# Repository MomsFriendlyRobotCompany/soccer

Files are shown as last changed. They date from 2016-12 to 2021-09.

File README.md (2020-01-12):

# Soccer

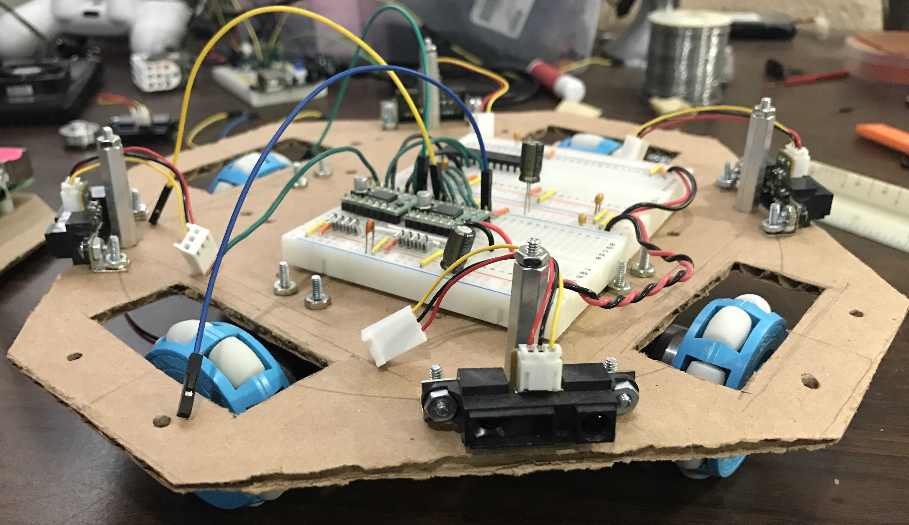
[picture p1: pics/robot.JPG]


My robot has seen better days and is currently torn appart. However, I plan to rebuild
it. Right now I am re-working it and put it into a like "bread board" configuration so
I can get everything setup again correctly.

## Documentation

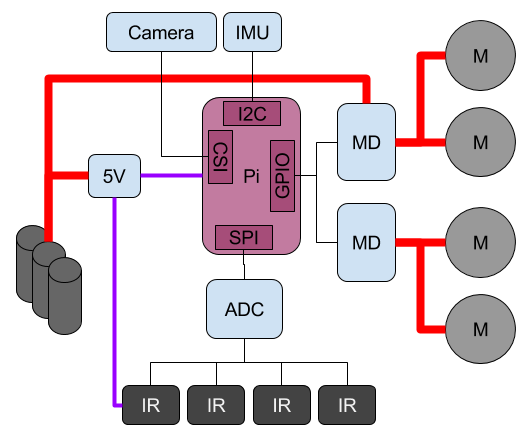
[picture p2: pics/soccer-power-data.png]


- main battery is a 12V NiMH
- a Pololu 5v, 2.6A buck converter supplying power to both RPi and the IR sensors
- the Pi is used to provide 3.3V to the IMU and ADC
- a MCP3208 ADC (8 channel, 12b) is used to read the IR sensors
- 4 geared DC brushed motors (138 rmp @ 12V) drive the robot
- Omni wheels from www.kornylak.com allow holonomic movement (no velocity constraint)
- Raspberry Pi Camera
- NXP IMU from Adafruit

### Other Docs

- [Markdown docs](./docs/Markdown)
- [Jupyter notebooks](./docs/ipython)

# Licenses

**Note:** The software, hardware, and documentation are under different licenses.

## Software

**The MIT License (MIT)**

Copyright (c) 2014 Kevin J. Walchko

Permission is hereby granted, free of charge, to any person obtaining a copy of
this software and associated documentation files (the "Software"), to deal in
the Software without restriction, including without limitation the rights to
use, copy, modify, merge, publish, distribute, sublicense, and/or sell copies
of the Software, and to permit persons to whom the Software is furnished to do
so, subject to the following conditions:

The above copyright notice and this permission notice shall be included in all
copies or substantial portions of the Software.

THE SOFTWARE IS PROVIDED "AS IS", WITHOUT WARRANTY OF ANY KIND, EXPRESS OR
IMPLIED, INCLUDING BUT NOT LIMITED TO THE WARRANTIES OF MERCHANTABILITY, FITNESS
FOR A PARTICULAR PURPOSE AND NONINFRINGEMENT. IN NO EVENT SHALL THE AUTHORS OR
COPYRIGHT HOLDERS BE LIABLE FOR ANY CLAIM, DAMAGES OR OTHER LIABILITY, WHETHER
IN AN ACTION OF CONTRACT, TORT OR OTHERWISE, ARISING FROM, OUT OF OR IN
CONNECTION WITH THE SOFTWARE OR THE USE OR OTHER DEALINGS IN THE SOFTWARE.

## Hardware and Documentation

<a rel="license" href="http://creativecommons.org/licenses/by-sa/4.0/">
	
</a>
<br />This work is licensed under a <a rel="license" href="http://creativecommons.org/licenses/by-sa/4.0/">Creative Commons Attribution-ShareAlike 4.0 International License</a>.

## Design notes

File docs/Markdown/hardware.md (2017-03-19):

# Body

My robot is broken up into 2 levels. The top level (seen on the left) which
will have the RPi, camera, and battery (easier to change/charge). The bottom
level will have motor drivers, power system, IR sensors, ADC, and compass.

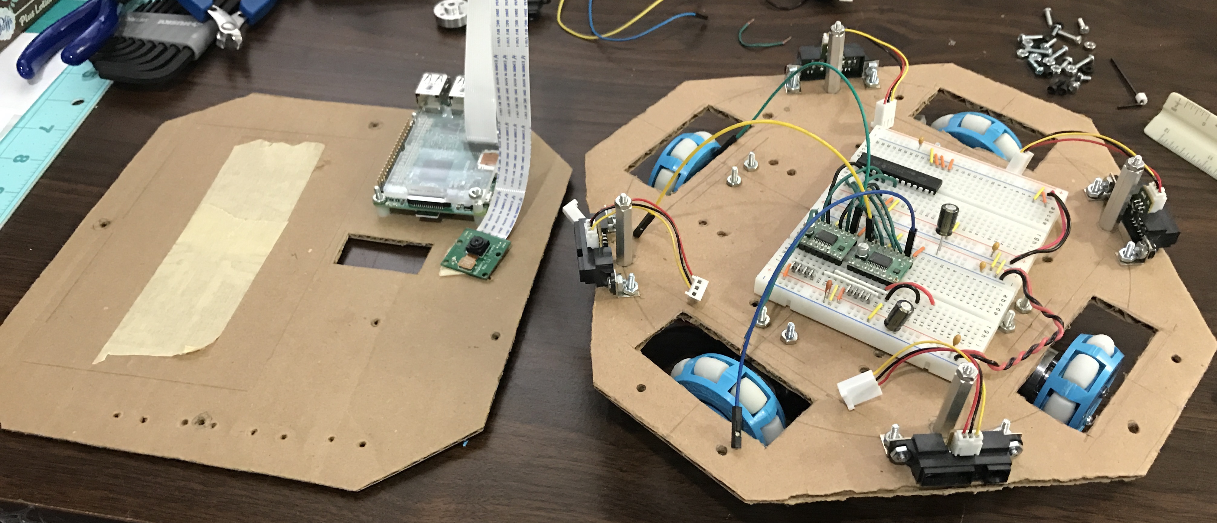
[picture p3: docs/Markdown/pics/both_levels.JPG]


A closer look at the bottom level is below:



The hubs and the wheels are joined together by some #4-40 x 1 inch bolts. I had
to drill a couple of holes through the center of the wheel so the bolts could
go through.

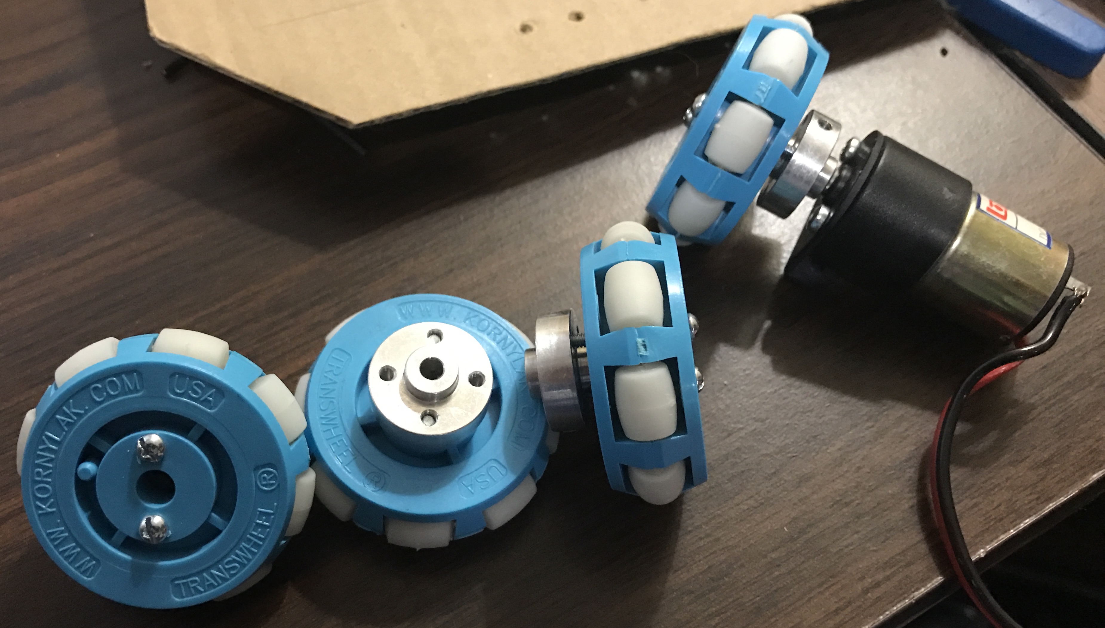
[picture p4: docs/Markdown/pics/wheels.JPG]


# Raspberry Pi

RPI 3

I am currently using a 1.2 GHz quad core [RPi 3](https://www.adafruit.com/products/3055) (ARMv8) as the main board running the lite version of Raspbian. It has on-board:

* 802.11n Wifi
* Bluetooth 4.1 BLE

## Camera Interface (CSI)

* [PiCamera](https://www.adafruit.com/products/3099) is used for video odometry (currently have version 1, 5 Mpixels but moving to 8 Mpixels)

## I2C

The following is on the I2C bus:

* [MCP23017 16b I/O Expander](https://www.adafruit.com/products/732): 0x20
* TBD - AHRS Compass ...need to get one

## GPIO

The RPi has both Pi pin numbers and BCM pin numbers assigned to its GPIO.

|BCM| Use  | Pi | Pi | Use |BCM|
|---|---|----|----|-----|---|
| | 3v3  |  1 |  2 | 5v  | |
| 2 | SDA  |  3 |  4 | 5v  | |
| 3 | SCL  |  5 |  6 | GND | |
| 4 | PWM0 |  7 |  8 | TX  | 14|
| | GND  |  9 | 10 | RX  | 15|
| 17| PWM1 | 11 | 12 | | 18|
| 27| PWM2 | 13 | 14 | GND | |
| 22| PWM3 | 15 | 16 | | 23|
| | 3v3  | 17 | 18 | | 24|
| 10| MOSI | 19 | 20 | GND | |
|  9| MISO | 21 | 22 | | 25|
| 11| SCLK | 23 | 24 | CE0 |  8|
| | GND  | 25 | 26 | CE1 |  7|
|  0| A0 | 27 | 28 | |  1|
|  5| B0 | 29 | 30 | GND | |
|  6| A1 | 31 | 32 | | 12|
| 13| B1 | 33 | 34 | GND | |
| 19| | 35 | 36 | | 16|
| 26| | 37 | 38 | | 20|
| | GND  | 39 | 40 | | 21|

# Sensors

* [Sharp GP2Y0A21YK0F IR](https://www.adafruit.com/products/164) sensors give 10-80 cm (3.9-31.5 in)
* Pololu [ACS711LC Current sensor](https://www.pololu.com/product/2198) measures up to +/-25 A and up to 30 V

# Motion

* Pololu [TB6612FNG Dual Motor Driver](https://www.pololu.com/product/713) provides 4.5-13.5V at 1A continuous (3A peak) current.
* Motors currently are 12V 130 rpm gear motors

# Parts

Here is a parts list of **key components** that I am using. I am not listing wires, bread boards, cables, etc. Also note, I have rounded up the costs (i.e., $4.95 => $5).

| Part | Source | Number | Item Cost | Sum | Notes |
| ---  | --- | --- | --- | --- | --- |
| RPi v3 | [Adafruit](https://www.adafruit.com) | 1 | $40 | $40 | Main board, has wifi and bluetooth already |
| Pi Camera | [Adafruit](https://www.adafruit.com) | 1 | $30 | $30 | Currently have old 5 Mpixel, will upgrade to newer 8 Mpixel |
| PWM/Servo Driver, 16 Channels, 12 bit resolution (PCA9685) | [Adafruit](https://www.adafruit.com) | 1 | $15 | $15 | Controls motors and servos over I2C |
| MCP23017 (16 I/O port expander, I2C) | [Adafruit](https://www.adafruit.com) | 1 | $3 | $3 | Used to increase the digital I/O |
| TB6612FNG Dual Motor Driver | [Pololu](https://www.pololu.com/product/713) | 2 | $5 | $10 | Logic level 3.3V, motors 4.5-13V @ 1A continous (3A peak) per channel |
| 5V, 5A Buck Converter (D24V50F5)  | [Pololu](https://www.pololu.com) | 1 | $15 | $15 | For powering my electronics |
| 12V, 5A Boost Converter (U3V50F12) | [Pololu](https://www.pololu.com) | 1 | $14 | $14 | For powering my motors (future 12V motors) |
| Sharp IR | [Pololu](https://www.pololu.com) | 8 | $10 | $80 | Range 10-80 cm |
| PS4 Controller | [Walmart](http://www.walmart.com) | 1 | $54 | $54 | |
| Micro SD (32 GB) | [Walmart](http://www.walmart.com) | 1 | $12 | $12 | |

---

<p align="center">
	<a rel="license" href="http://creativecommons.org/licenses/by-sa/4.0/">
		
	</a>
	<br />This work is licensed under a <a rel="license" href="http://creativecommons.org/licenses/by-sa/4.0/">Creative Commons Attribution-ShareAlike 4.0 International License</a>.
</p>

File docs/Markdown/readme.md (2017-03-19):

# Documentation

- [Software](./software.md)
- [Hardware](./hardware.md)
- [PyGecko](./pygecko.md)
- [History](./history.md)

---

A highlevel overview of how the robot works is shown below

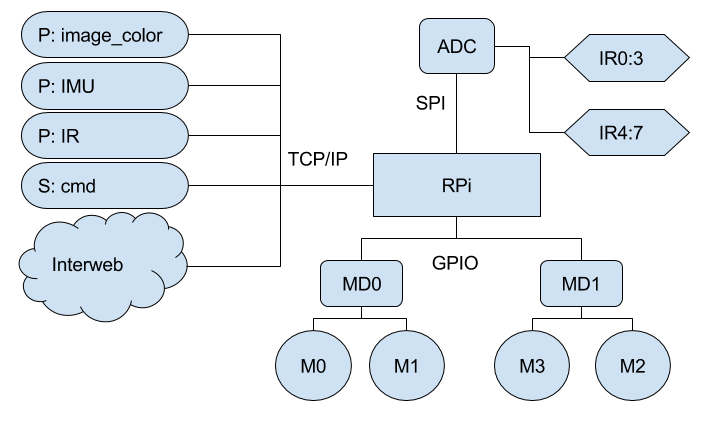
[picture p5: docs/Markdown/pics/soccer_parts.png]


- P: publish pygecko messages
- S: subscribe to pygecko messages

The publish and subscribe architecture is drawn from ROS ([Robotic Operating System](http://www.ros.org/)) where multiple/modular processess run a robot and
they communicate via a publish/subscribe architecture. I don't use ROS because
it is a pain to install on systems it is not designed for. I use [PyGecko](https://github.com/walchko/pygecko) which implements some of the basic
useful features of ROS.

A **nonholonomic system** in physics and mathematics is a system whose state
depends on the path taken in order to achieve it. [Ref](https://en.wikipedia.org/wiki/Nonholonomic_system)
Think about how a car (nonholonomic) must parallel park ... wouldn't it be easier
if it could drive sideways! Basically, a car has a velocity constraint in its
movement.

Since this robot can move in any direction and is not required to follow a specific
path, it is a **holonomic system** and is a common design in robotic soccer.

---

<p align="center">
	<a rel="license" href="http://creativecommons.org/licenses/by-sa/4.0/">
		
	</a>
	<br />This work is licensed under a <a rel="license" href="http://creativecommons.org/licenses/by-sa/4.0/">Creative Commons Attribution-ShareAlike 4.0 International License</a>.
</p>

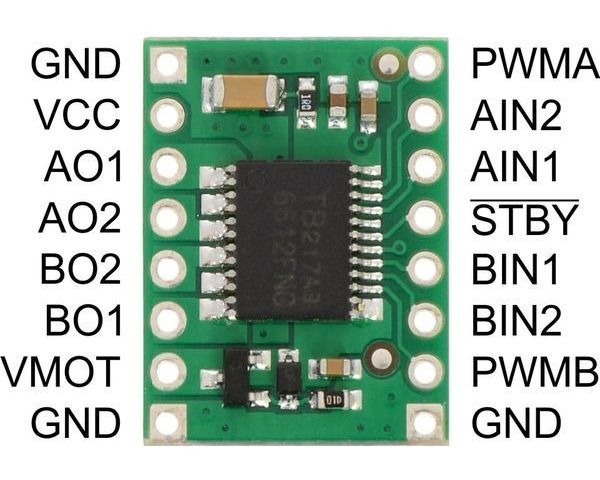
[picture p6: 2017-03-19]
docs/motor_driver/TB6612FNG.jpg

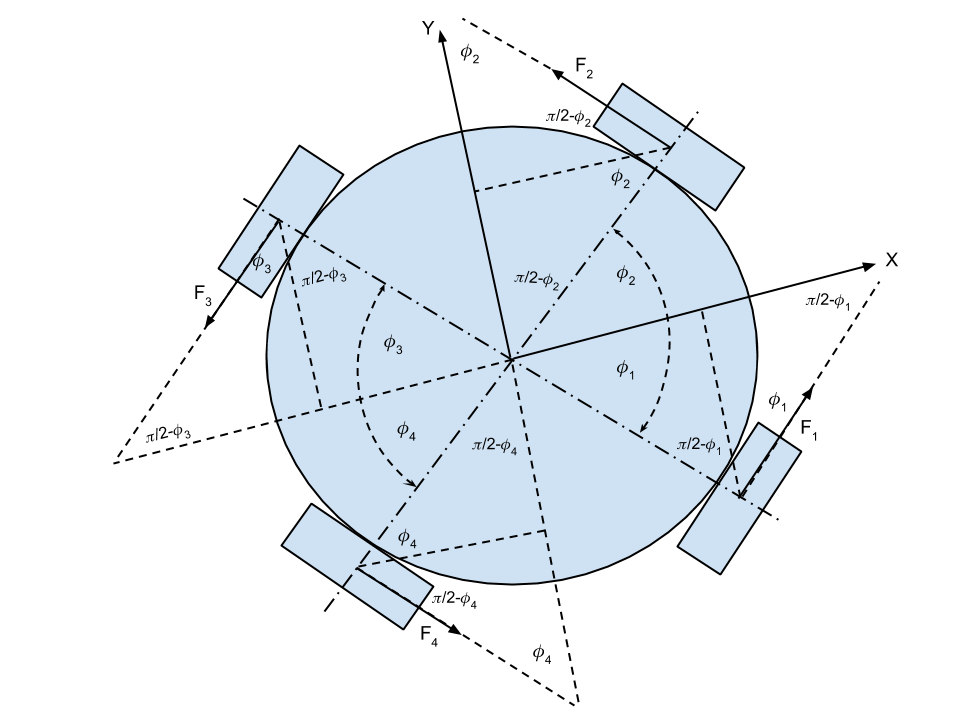
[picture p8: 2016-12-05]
docs/ipython/pics/omni_robot_force_cs.png

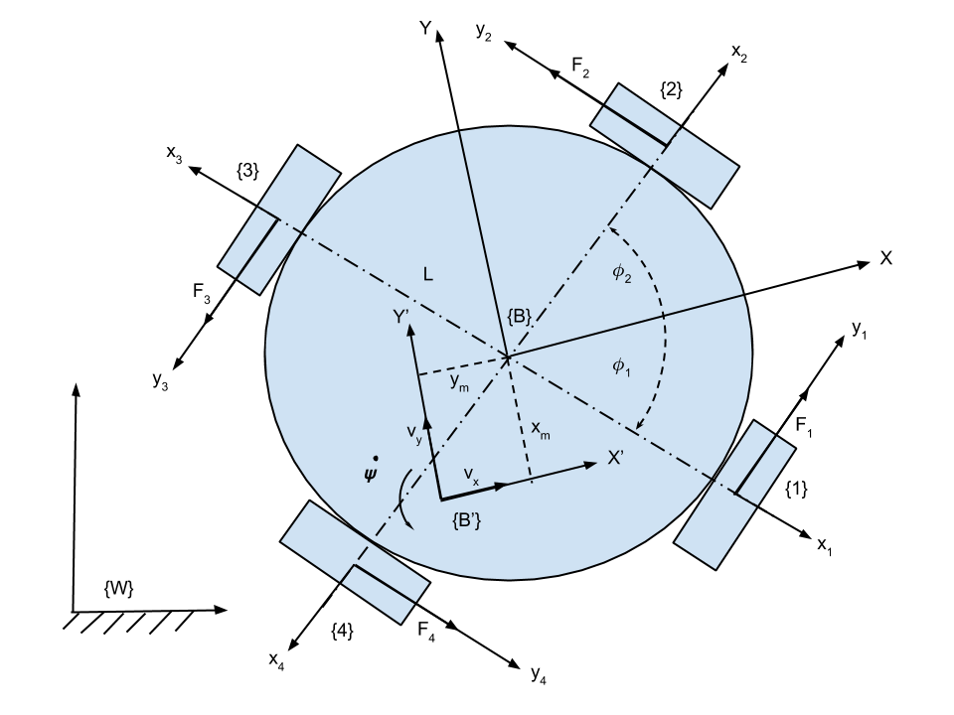
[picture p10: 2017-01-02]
docs/ipython/pics/omni_robot_cs.png

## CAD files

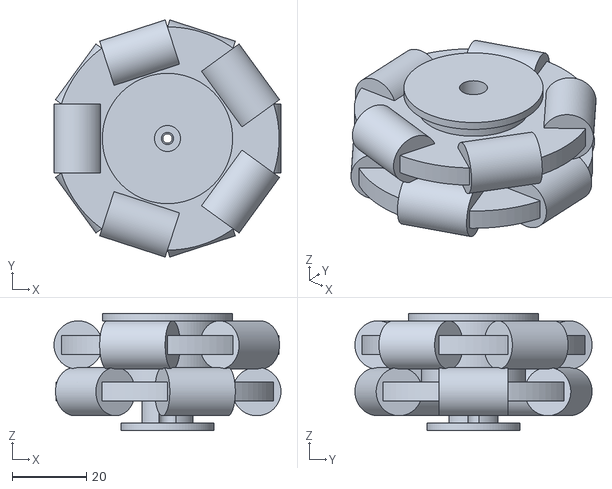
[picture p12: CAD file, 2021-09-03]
mechanical/omni-wheel.stl
61.0 x 63.7 x 31.5

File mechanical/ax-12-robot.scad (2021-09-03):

$fn=90;

module ax12(){
    // sort of center mass
    color("dimgray") translate([0,0,0]) import("DYNAMIXEL_AX-12A.STL");
    color("dimgray") translate([0,0,20]) import("omni-wheel.stl");
}

module base(dia){
    corner = 70;
    sx = 30;
    sy = 34;
    difference()
    {
        /* cylinder(d=dia, h=4); */
        translate([-dia/2,-dia/2,0]) cube([dia,dia,4]);
        /* translate([0,0,-1]) cylinder(d=dia/3, h=6); */
        for (i=[45, 45+90, 45+180, 45+270]){
            color("red") rotate([0,0,i]) translate([100,0,0]) translate([-corner/2,-corner/2,-1]) cube([corner,corner,6]);
            color("red") rotate([0,0,i]) translate([40,0,0]) translate([-sx/2,-sy/2,-1]) cube([2*sx,sy,6]);
        }
    }
}

base(175);


for (i=[45, 45+90, 45+180, 45+270]){
    rotate([0,0,i]) translate([-45,0,0]) rotate([0,-90,0]) ax12();
}

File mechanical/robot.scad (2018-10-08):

$fn=90;

module M3(t){
    dia = 3.5;
    sdia = 8.5;  // counter sink dia
    cylinder(3*t, d=dia, center=true);  // M3
    translate([0,0,2]) cylinder(3*t, d=sdia, center=false);  // screw driver
}

module M2(t){
    dia = 2.5;
    sdia = 6;  // counter sink dia
    cylinder(3*t, d=dia, center=true);  // M2
    translate([0,0,2]) cylinder(3*t, d=sdia, center=false);  // screw driver
}

// DC motor
module motor(){
    rotate([0,90,0]) {
        color("silver") translate([0,0,-16]) cylinder(h=12,d=4);  // shaft
        color("gray") translate([0,0,-4]) cylinder(h=4, d=9);     // nubbin
        difference(){
            color("gray") cylinder(h=20, d=25);                   // gears
            translate([21/2,0,-1]) cylinder(h=5, d=3);            // mounting hole
            translate([-21/2,0,-1]) cylinder(h=5, d=3);           // mounting hole
        }
        color("silver") translate([0,0,20]) cylinder(h=22, d=23); // motor
        color("gray") translate([0,0,42]) cylinder(h=3, d=10);    // motor nubbin
    }
}

// metal hub between wheel and motor
module hub(){
    color("silver") rotate([0,90,0]) {
        cylinder(h=3, d=9);
        translate([0,0,3]) cylinder(h=6, d=22);
        translate([0,0,9]) cylinder(h=3, d=9);
    }
}

// omni wheel
module wheel(){
    rotate([0,90,0]) color("lightblue") difference(){
        cylinder(h=17, d=49, center=true);
        cylinder(h=20, d=7, center=true);
    }

    for(a = [0:7]){
        rotate([a*45,0,0]) translate([0,22,0]) color("white") cylinder(h=12,d=9, center=true);
    }
}

// combined motor, hub, and wheel assembly
module wheel_seg(){
    motor();
    translate([-16,0,0]) hub();
    translate([-16-17/2,0,0]) wheel();
}

// mounting frame for motor
module motor_mnt(){
    difference(){
        cube([2,30,30]);
    }
}

module ir_mnt(){
    translate([-3/2,-25/2,0]) cube([3,25,10]);
}

module motor_plate(dia, draw=false){
    if (draw){
        translate([0,0,25/2+4]){
            mdis = [-dia/4-5,0,0];
            translate(mdis) wheel_seg();
            rotate([0,0,90]) translate(mdis) wheel_seg();
            rotate([0,0,180]) translate(mdis) wheel_seg();
            rotate([0,0,270]) translate(mdis) wheel_seg();
        }
    }

    difference(){
        cylinder(h=3, d=dia);

        // center
        cylinder(h=9, d=dia/2, center=true);

        // wheel cut outs
        translate([80,0,0]) cube([20,55,20], center=true);
        rotate([0,0,90]) translate([80,0,0]) cube([20,55,20], center=true);
        rotate([0,0,180]) translate([80,0,0]) cube([20,55,20], center=true);
        rotate([0,0,270]) translate([80,0,0]) cube([20,55,20], center=true);

        // mounts
        for(a=[0:3]){
            rotate([180,0,0]) rotate([0,0,90*a+45]) translate([0.8*dia/2,0,-3]) M3(20);
        }
    }

    /* for(a=[0:3]){
        rotate([180,0,0]) rotate([0,0,90*a+45]) translate([0.8*dia/2,0,-3]) M3(20);
    } */

    for(a=[0:3]){
        rotate([0,0,90*a]) translate([-57.5,-15,0]) motor_mnt();
        // rotate([0,0,90*a+45]) translate([0.8*dia/2,0,3]) ir_mnt();
    }
}

motor_plate(200, false);

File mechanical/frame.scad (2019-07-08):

module wheel(){
    thick = 17;  // mm
    dia = 50.8;
    cylinder(h=thick, d=dia);
}

module motor(){
    cylinder(h=60, d=25);
}

module mw(angle){
    rotate([90,0,angle]){
        motor();
        translate([0,0,60]) wheel();
    }
}

translate([0,-20,0]) mw(0);
translate([20,0,0]) mw(90);
translate([0,20,0]) mw(180);
translate([-20,0,0]) mw(270);

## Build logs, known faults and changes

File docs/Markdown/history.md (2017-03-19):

# History

Long ago, I hacked some old servos to make them continue turn and used them
to drive this robot. They worked okay, but I wanted to replace them with some
good DC motors.

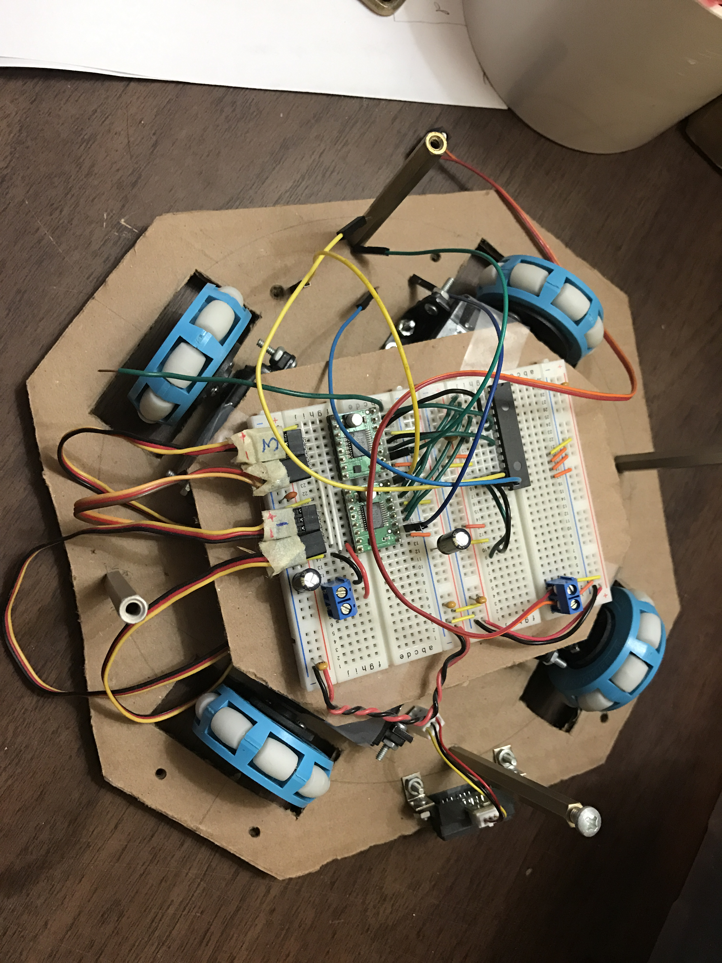
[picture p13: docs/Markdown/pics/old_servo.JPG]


This was a simple breadboard I setup to test out my new DC motors that replaced
the old hacked servos.

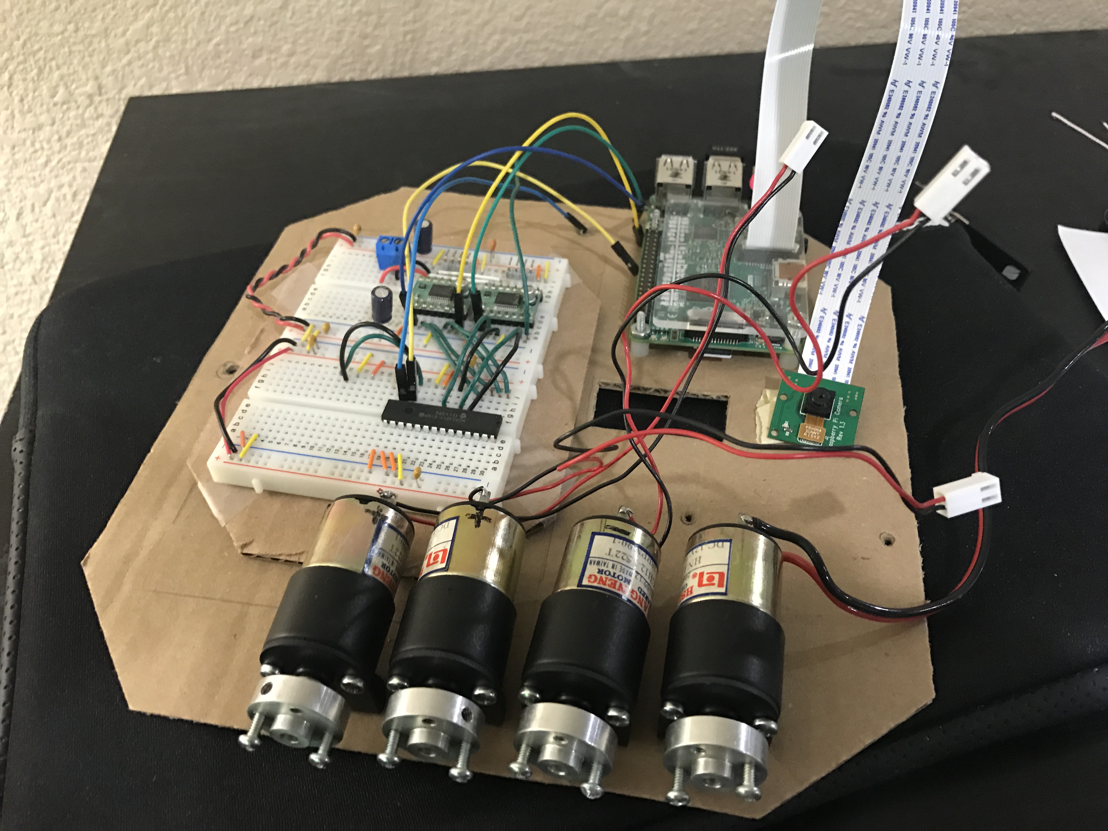
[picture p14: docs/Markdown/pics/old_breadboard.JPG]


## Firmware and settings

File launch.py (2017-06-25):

#!/usr/bin/env python
# 7 Jan 2017

from __future__ import division
from __future__ import print_function
from multiprocessing import Process
from Soccer import SoccerRobot
from pygecko import ZmqClass as zmq
from pygecko import Messages as Msg
import time


def soccer():
	md_pins = [
		17, 18,  # m0 pwm a, b
		22, 23,  # m1 pwm a, b
		24, 25,  # m0 a, b
		26, 27   # m1 a, b
	]
	robot = SoccerRobot(md_pins)

	cmd_sub = zmq.Sub(topics=['cmds'], connect_to=('0.0.0.0', 9000))
	# telemetry_pub = zmq.Pub(bind_to=('0.0.0.0', 9010))

	while True:
		robot.loop_once()

		# get info
		topic, msg = cmd_sub.recv()
		if msg:
			print('msg:', topic, msg)

			if topic == 'quit':
				self.shutdown()
				break
			elif topic == 'cmd':
				# need logic for command
				cmd = self.makeCmd(msg)
				self.md.setMotors(*cmd)


def main():
	try:
		robot = Process(target=soccer).start()
	except KeyboardInterrupt:
		robot.join(0.1)
		if robot.is_alive():
			robot.terminate()

if __name__ == '__main__':
	main()

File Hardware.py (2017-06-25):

#!/usr/bin/python

from __future__ import division
from __future__ import print_function
import platform
import os
from mcp3208 import MCP3208

# if platform.system().lower() == 'linux' and 'CI' not in os.environ:
try:
	if 'CI' in os.environ or platform.system() != 'Linux':
		raise ImportError()
	# from Adafruit_MCP230XX import Adafruit_MCP230XX as MCP230XX
	import RPi.GPIO as GPIO
	from RPi.GPIO import PWM

except ImportError:
	from fake_rpi import GPIO
	from fake_rpi.PWM import PWM


class AnalogIR(object):
	"""
	Read IR sensors on adc inputs
	"""
	def __init__(self):
		self.adc = MCP3208()
		self.ir = {}
		for key in ['front', 'right', 'back', 'left']:
			self.ir[key] = 0

	def read(self):
		for pin, key in enumerate(self.ir):
			# ir.append(self.adc.read(pin))
			# print('read >>', pin, key)
			self.ir[key] = self.adc.read(pin)

		return self.ir


class DigitalIR(object):
	"""
	Read IR sensors on digital inputs

	Pololu sds01a 0-5 cm pwr 3V output max 3V
	Sharp xxx 0-15 cm pwr 5V output max 3V - digital gives 3 inch range
	"""
	def __init__(self, pins):
		GPIO.setwarnings(False)
		GPIO.setmode(GPIO.BCM)
		self.pins = pins
		GPIO.setup(self.pins, GPIO.IN)

	def read(self):
		ir = [0]*len(self.pins)
		# for p in self.pins: ir.append(GPIO.input(p))
		for pin in range(self.pins):
			ir[pin] = self.adc.read(pin)
		return ir


class MotorDriver(object):
	"""
	This uses RPI.GPIO
	"""
	STOP    = 0
	FORWARD = 1
	REVERSE = 2
	COAST   = 3

	def __init__(self, pwm0, pwm1, pwm2, pwm3, a0, b0, a1, b1):
		"""
		"""
		# self.mux = MCP230XX(0x20, 16, 1)
		#
		# for pin in range(0, 15):
		# 	self.mux.config(pin, GPIO.OUT)

		# this can be:
		# BOARD -> Board numbering scheme. The pin numbers follow the pin numbers on header P1.
		# BCM -> Broadcom chip-specific pin numbers.
		GPIO.setmode(GPIO.BCM)  # Pi cover uses BCM pin numbers, GPIO.BCM = 11
		GPIO.setup([pwm0, pwm1, pwm2, pwm3], GPIO.OUT)  # GPIO.OUT = 0

		freq = 100.0  # Hz
		self.motor0 = PWM(pwm0, freq)
		self.motor1 = PWM(pwm1, freq)
		self.motor2 = PWM(pwm2, freq)
		self.motor3 = PWM(pwm3, freq)

		self.motor0.start(0)
		self.motor1.start(0)
		self.motor2.start(0)
		self.motor3.start(0)

		self.ctl = [a0, b0, a1, b1]

		GPIO.setup([a0, b0, a1, b1], GPIO.OUT)  # GPIO.OUT = 0
		# self.a0 = a0
		# self.b0 = b0
		# self.a1 = a1
		# self.b1 = b1

		# GPIO.output(self.a0, GPIO.LOW)
		# GPIO.output(self.b0, GPIO.LOW)
		# GPIO.output(self.a1, GPIO.LOW)
		# GPIO.output(self.a1, GPIO.LOW)

		for pin in self.ctl:
			GPIO.output(pin, GPIO.LOW)

	def __del__(self):
		print('motor drive ... bye')
		self.allStop()
		self.motor0.stop()
		self.motor1.stop()
		self.motor2.stop()
		self.motor3.stop()
		GPIO.cleanup()

	def clamp(self, x, minimum=0, maximum=100):
		"""
		Clamps a PWM from 0-100 and puts it into the right servo usec timing.
		"""
		# minimum = 0
		# maximum = 100
		return 0 if x == 0 else max(minimum, min(x, maximum))

	def setMotors(self, m0, m1, m2, m3):
		"""
		Takes 4 tuples (shown below) for each motor.

		tuple: (dir, duty)

		MotorDriver.STOP    = 0
		MotorDriver.FORWARD = 1
		MotorDriver.REVERSE = 2
		MotorDriver.COAST   = 3
		"""
		# if not 'dir' in m0 or not 'duty' in m0: return
		# low = 0
		# high = 100

		# print(m0, m1, m2, m3)

		# set mux
		# val = m3['dir'] << 6 | m2['dir'] << 4 | m1['dir'] << 2 | m0['dir']
		# val = m3[0] << 6 | m2[0] << 4 | m1[0] << 2 | m0[0]
		# self.mux.write8(val)
		# GPIO.output(self.a0, m0[0])
		# GPIO.output(self.b0, m1[0])
		# GPIO.output(self.a1, m2[0])
		# GPIO.output(self.b1, m3[0])
		#
		# # set pwm
		# pwm = self.clamp(m0[1])
		# self.motor0.ChangeDutyCycle(pwm)
		#
		# pwm = self.clamp(m1[1])
		# self.motor1.ChangeDutyCycle(pwm)
		#
		# pwm = self.clamp(m2[1])
		# self.motor2.ChangeDutyCycle(pwm)
		#
		# pwm = self.clamp(m3[1])
		# self.motor3.ChangeDutyCycle(pwm)

		for pin, cmd, motor in zip(self.ctl, [m0, m1, m2, m3], [self.motor0, self.motor1, self.motor2, self.motor3]):
			GPIO.output(pin, cmd[0])
			pwm = self.clamp(cmd[1])
			motor.ChangeDutyCycle(pwm)

	def allStop(self):
		"""
		"""
		# self.mux.write8(0)
		# GPIO.output(self.a0, GPIO.LOW)
		# GPIO.output(self.b0, GPIO.LOW)
		# GPIO.output(self.a1, GPIO.LOW)
		# GPIO.output(self.a1, GPIO.LOW)
		for pin in self.ctl:
			GPIO.output(pin, GPIO.LOW)

		stop = (0, 0)
		self.setMotors(stop, stop, stop, stop)

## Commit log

2016-11-19 init ... sort of ... major re-org
    I split out my different robots into their own repositories. This is
    really an old robot that I have worked on for a long time … it just has
    a new home
2018-05-19 first mechanical design
    [robot.scad]
2021-09-03 stl and model update
    [ax-12-robot.scad, omni-wheel.stl]

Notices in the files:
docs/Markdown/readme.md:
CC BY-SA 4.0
